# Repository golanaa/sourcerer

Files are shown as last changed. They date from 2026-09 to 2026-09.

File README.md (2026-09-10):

# Sourcerer

Sourcerer is a digitally controlled solar MPPT power source with miner-aware
power budgeting and an optional wall-assist path.

Sourcerer is being developed as an open reference platform for solar-powered
Bitcoin mining. It prioritizes safe power-supply behavior while allowing the
converter and a connected Bitaxe to coordinate around available solar power.

An optional isolated wall-supply path can maintain load operation when solar
power is insufficient, while available solar power displaces wall power.

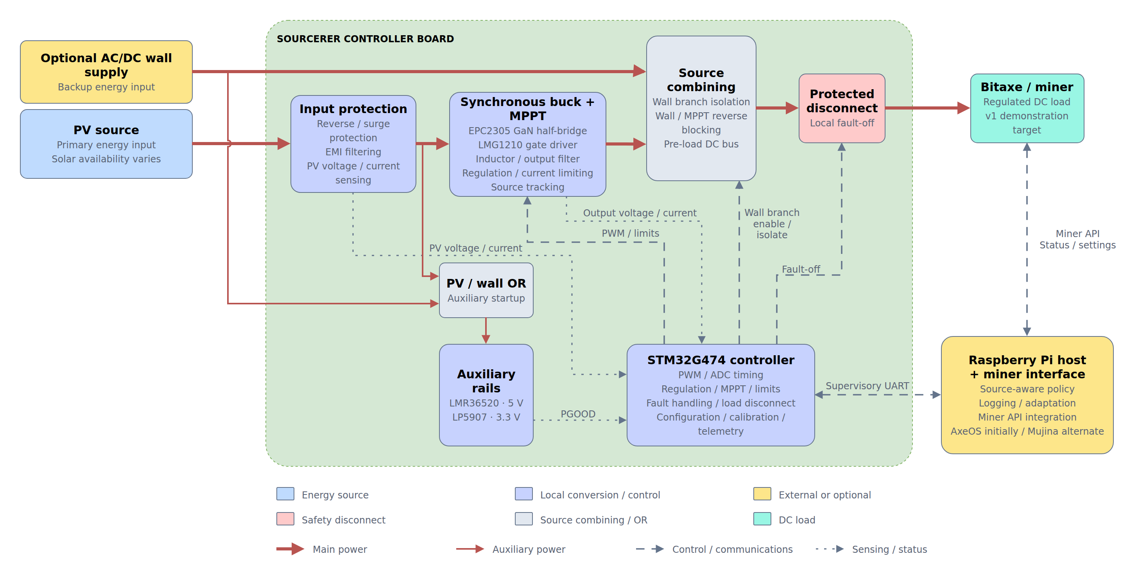
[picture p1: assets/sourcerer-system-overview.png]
Sourcerer v1 system overview showing power paths, local control, and miner coordination


## Backend-Neutral Miner Integration

Sourcerer uses a wired, backend-neutral supervisory interface rather than
embedding miner-specific protocols in the converter firmware. Initial
development connects Sourcerer over UART to a Raspberry Pi-class host, which
can interface with either:

- Bitaxes running stock AxeOS through the AxeOS network API.
- Miners managed by Mujina through the Mujina API.

This separation keeps converter regulation and protection local while allowing
the host-side coordination software to evolve independently. It also preserves
a path to a future UART-to-Wi-Fi/Ethernet gateway capable of communicating with
multiple AxeOS or Mujina instances.

## v1 Goals

- Convert available solar power into a regulated supply for a Bitaxe.
- Keep converter safety and regulation independent of external communications.
- Allow an optional isolated wall supply to fill a solar-power shortfall.
- Report power-system telemetry and demonstrate basic coordinated control with a connected Bitaxe.
- Provide an open development platform for experimenting with source-aware Bitcoin mining.

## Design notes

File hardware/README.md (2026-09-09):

# Sourcerer hardware

Open `pcb/sourcerer.kicad_pro` with KiCad 10.0.4 or later, with the standard
KiCad symbol and footprint libraries installed. This is the working design,
not an export. The CubeMX configuration is `../firmware/sourcerer.ioc`.

## Schematic sheets

The project uses three flat top-level sheets:

1. **Sourcerer** (`sourcerer.kicad_sch`) - editable overview and general information.
2. **Power** (`power.kicad_sch`) - power conversion and supporting circuitry.
3. **Microcontroller** (`microcontroller.kicad_sch`) - controller and supporting circuitry.

The overview contains only graphics and text; it adds no electrical connections.
Open the project to load the complete sheet set.

## Separate shared-library checkout

Keep the Sourcerer checkout and shared component-library checkout beside one
another. Use `ocpm-library` as the directory name for the library checkout:

```text
work/
├── sourcerer/
│   └── hardware/pcb/sourcerer.kicad_pro
└── ocpm-library/
    ├── verified/
    │   ├── verified.kicad_sym
    │   ├── verified.pretty/
    │   └── verified.3dshapes/
    └── unverified/
        ├── unverified.kicad_sym
        ├── unverified.pretty/
        └── unverified.3dshapes/
```

The project library tables and `OCPM_3DMODEL_DIR` project text variable point
to that sibling directory. No personal absolute path or manual global-library
registration is required. Open the project rather than a detached board so
KiCad loads the project settings. Reopen an already-open project after changing
these paths.

### Pinned library revision

[`ocpm-library.lock`](ocpm-library.lock) records the library repository and exact
commit expected by this Sourcerer revision. Use that commit, not whichever
library version happens to be newest. The lock file documents the dependency;
KiCad does not read or enforce it automatically.

After cloning Sourcerer, run these commands **from the Sourcerer repository root**
to create a separate sibling library checkout and select the pinned revision:

```sh
git clone https://github.com/golanaa/ocpm-library.git ../ocpm-library
git -C ../ocpm-library checkout --detach "$(sed -n 's/^commit=//p' hardware/ocpm-library.lock)"
```

If the sibling checkout already exists, skip cloning. After switching Sourcerer
branches or pulling changes, check its lock file and select the recorded revision:

```sh
git -C ../ocpm-library fetch origin
git -C ../ocpm-library checkout --detach "$(sed -n 's/^commit=//p' hardware/ocpm-library.lock)"
```

These commands use a detached checkout to reproduce the recorded library
revision. Create a library branch before making component changes; preserve any
local work before switching revisions.

### Updating the dependency

When a design change needs new or revised library components, commit and publish
those components in the library repository first. Update the full `commit=` hash
in `ocpm-library.lock` and commit that pin alongside the Sourcerer design change.
The pinned commit must be available from the recorded repository. Ordinary design
changes that use the same library revision do not require a pin update.

Sourcerer contains no copied component libraries or Git submodule. The separate
checkout remains the library source; updating the pin does not copy any files.

Placed symbols and footprints remain embedded in the schematic and board.
Applying library revisions to them is still an explicit KiCad action. Existing
parts do not change merely because you pulled a newer library. `Unverified`
components remain candidates; availability is not an approval.

## Development state

This is unfinished hardware, not a fabrication release. The PCB is currently an
empty layout scaffold, so assigned footprints must still be obtained from the
shared library when populating it. The CubeMX file is peripheral planning, not
completed closed-loop firmware. Existing circuit/ERC findings remain design
work; no circuitry or approval states are changed by this directory setup.

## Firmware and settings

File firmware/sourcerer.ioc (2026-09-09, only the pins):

Mcu.UserName=STM32G474CBTx
PA0.GPIO_Label=VIN_SENSE
PA0.Signal=ADC1_IN1
PA1.GPIO_Label=IIN_SENSE
PA1.Signal=ADC1_IN2
PA12.GPIO_Label=GATE_FAULT_FAST
PA12.Signal=HRTIM1_FLT1
PA13.GPIO_Label=SWDIO
PA13.Signal=SYS_JTMS-SWDIO
PA14.GPIO_Label=SWCLK
PA14.Signal=SYS_JTCK-SWCLK
PA15.GPIO_Label=PG_5V0
PA15.Signal=GPIO_Input
PA2.GPIO_Label=VOUT_SENSE
PA2.Signal=ADC1_IN3
PA3.GPIO_Label=TEMP_CONVERTER
PA3.Signal=ADC1_IN4
PA4.GPIO_Label=OCP_THRSHLD
PA4.Signal=COMP1_INM
PA5.GPIO_Label=OCP_DAC
PA5.Signal=COMP_DAC12_group
PA6.GPIO_Label=ZCS_DAC
PA6.Signal=COMP_DAC21_group
PA7.GPIO_Label=IOUT_SENSE
PA7.Signal=ADC2_IN4
PA8.GPIO_Label=BUCK_PWM_A
PA8.Signal=HRTIM1_CHA1
PA9.GPIO_Label=BUCK_PWM_B
PA9.Signal=HRTIM1_CHA2
PB0.GPIO_Label=ZCS_SNS
PB0.Signal=COMP4_INP
PB1.GPIO_Label=OCP_SNS
PB1.Signal=COMP1_INP
PB10.GPIO_Label=BAP_UART_TX
PB10.Signal=USART3_TX
PB11.GPIO_Label=BAP_UART_RX
PB11.Signal=USART3_RX
PB12.GPIO_Label=WALL_V_SENSE
PB12.Signal=ADC4_IN3
PB13.GPIO_Label=TEMP_SPARE
PB13.Signal=ADC3_IN5
PB14.GPIO_Label=WALL_I_SENSE
PB14.Signal=ADC4_IN4
PB15.GPIO_Label=BUS_V_SENSE
PB15.Signal=ADC4_IN5
PB2.GPIO_Label=ZCS_THRSHLD
PB2.Signal=COMP4_INM
PB3.GPIO_Label=WALL_BRANCH_EN
PB3.Signal=GPIO_Output
PB5.GPIO_Label=LOAD_DISCONNECT_EN
PB5.Signal=GPIO_Output
PB6.GPIO_Label=DEBUG_UART_TX
PB6.Signal=USART1_TX
PB7.GPIO_Label=DEBUG_UART_RX
PB7.Signal=USART1_RX
PB9.GPIO_Label=LOAD_FAULT_STATUS
PB9.Signal=GPIO_Input
PC13.GPIO_Label=SYSTEM_STATUS_LED
PC13.Signal=GPIO_Output
PC14-OSC32_IN.GPIO_Label=LOCAL_ENABLE
PC14-OSC32_IN.Signal=GPIO_Input
PC15-OSC32_OUT.GPIO_Label=LOCAL_FAULT_CLEAR
PC15-OSC32_OUT.Signal=GPIO_Input

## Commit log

2026-09-09 Track working hardware and CubeMX project with portable dependencies
    Use the actual hardware/pcb design and project-pinned libraries. Preserve component content and metadata; exclude private notes and editor artifacts.
    [power_path.kicad_sch, sourcerer_v1.kicad_pcb, sourcerer_v1.kicad_sch]
2026-09-09 Revert "Track working hardware and CubeMX project with portable dependencies"
    This reverts commit e999737d51727bec97f9b970c76c4c93f2db8fb2.
    [power_path.kicad_sch, sourcerer_v1.kicad_pcb, sourcerer_v1.kicad_sch]
2026-09-09 Add working Sourcerer design with separate shared library
    Track the overview, Power and Microcontroller sheets, KiCad project and PCB scaffold, and CubeMX configuration. Resolve OCPM components through a sibling ocpm-library checkout; keep private documentation, captures and backups excluded.
    [microcontroller.kicad_sch, power.kicad_sch, sourcerer.kicad_pcb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]
2026-09-09 Pin shared OCPM library revision and document checkout
2026-09-10 Assign PB13 to delivered-load voltage sensing
2026-09-18 Replace legacy passive Specs with verified exact-MPN components
    Migrate 51 instances across 20 identities and advance the public library pin to 8a4c96de. Preserve component references, UUIDs, placement, DNP flags, shared package geometry/models and exact pin-to-net connectivity. All ERC findings match baseline; PCB and unrelated components unchanged. Includes per-reference replacement report.
2026-09-23 Update precision current-sense circuit and pin published OCPM library
2026-10-16 Add TPS48110 disconnect, OVP, and discharge design; update MCU and power schematics
    Documents the buck high-side short-circuit fault, programmable output
    overvoltage protection, and controlled output discharge, and records the
    saved schematic changes.
